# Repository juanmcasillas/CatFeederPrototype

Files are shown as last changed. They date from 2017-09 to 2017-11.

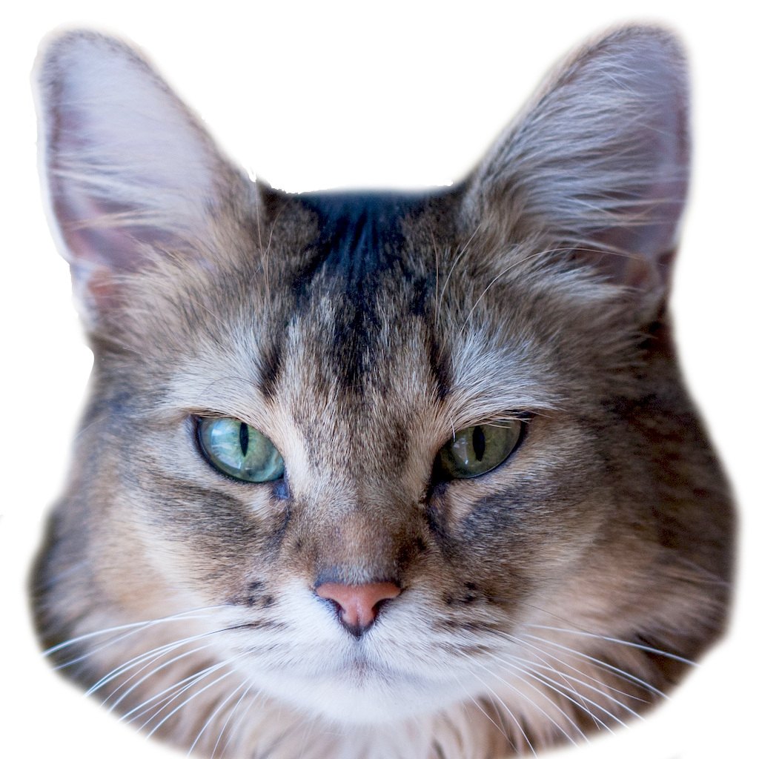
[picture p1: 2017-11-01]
python/webserver/www/photos/trans/neko.png

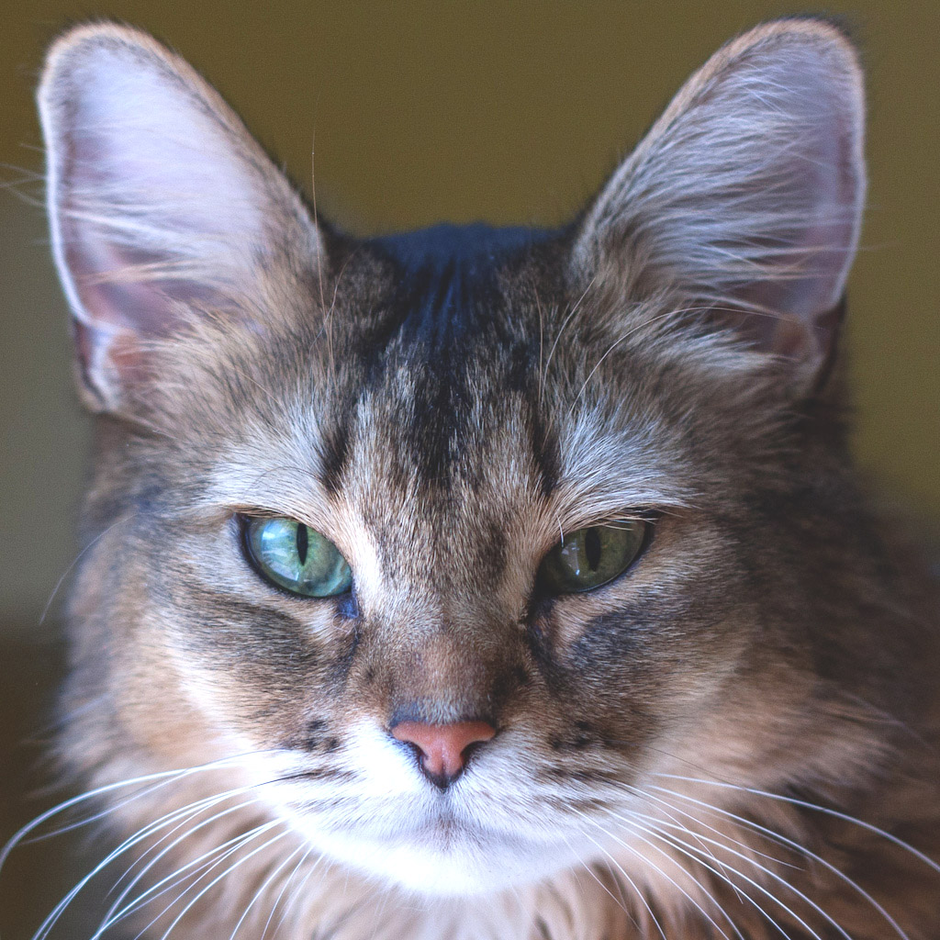
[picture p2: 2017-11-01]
python/webserver/www/photos/neko.jpg

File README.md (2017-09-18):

# CatFeeder
Automatic pet feeder, with artificial vision detection, rule based. Managed from a Web Server. Fully automated.

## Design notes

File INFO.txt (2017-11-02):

CatFeeder.

How to write a Cat Feeder, with lot of componentes.

pip install python-dateutil
pip install nanpy
sudo pip install git+https://github.com/dpallot/simple-websocket-server.git
pip install pytz
pip install tzlocal
  
------------------
1) CAT RECOGNIZER
------------------

IDS

01  ELI
02  FIRULAIS
03  NEKO

GOAL: recognize what of the three cats are lurking arround.

Using opencv2 (3.1.0) on raspberry Pi 3 with camera module 2.0 (raspbian jessie)

We have to train the classifier with the cats. So we need a source of
images. We can create a video, or add a bunch of images. So the flow:

[VIDEO] -> Convert to Images -> Train -> [Match]

[Match] can be realtime (VIDEO) or by picture (OFFLINE).

process_video.py
----------------

Get a video, extract cat faces, dump in the filesystem.

train_video.py
--------------

do the same thing, but trains a whole video. This is useful for one cat,
but we need to train 3 different videos (three cats) so work on that.

train_images.py
test_images.py

Nanpy:

git clone https://github.com/nanpy/nanpy-firmware.git
cd nanpy-firmware
./configure.sh

Managing a DC motor with Arduino
(Extracted from a CD ROM)

How to move it:

ARDUINO_PWM_IN	ARDUINO_DIRA_IN ARDUINO_DIRB_IN		GIRO
	5v				5v				0v				left
	5v				0v				5v				right
	5v				0v				0v				stop
	5v				5v				5v				NOT_ALLOWED
	0v				x				x				stop

https://ardubasic.wordpress.com/2014/05/23/control-de-motores-de-cc-con-l293d/
http://communityofrobots.com/tutorial/kawal/how-drive-dc-motor-using-l293d-arduino

OPENCV_PYTHON (windows)

set PATH=C:\Python27\DLLs;%PATH%

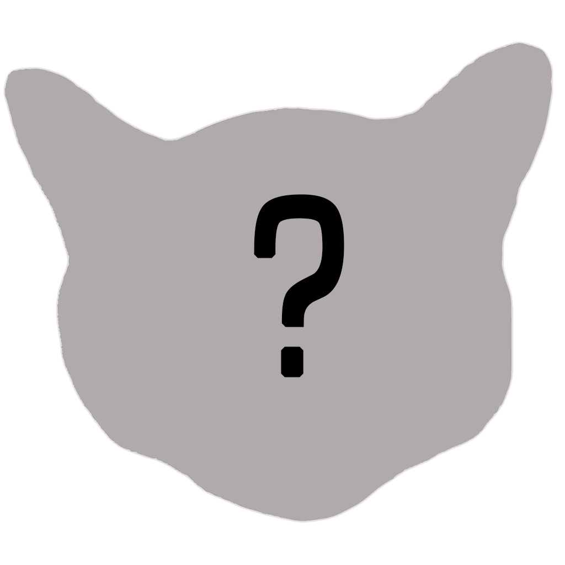
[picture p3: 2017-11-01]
python/webserver/www/photos/trans/unknown.png

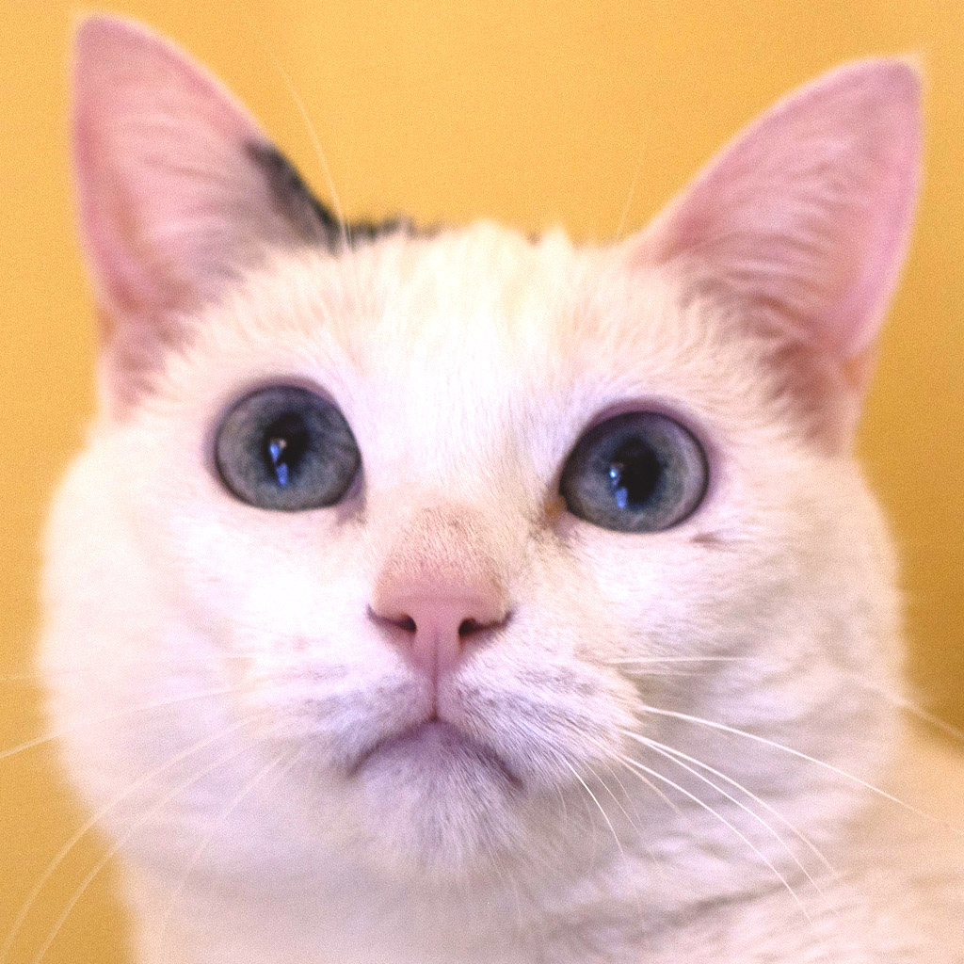
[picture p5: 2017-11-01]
python/webserver/www/photos/eli.jpg

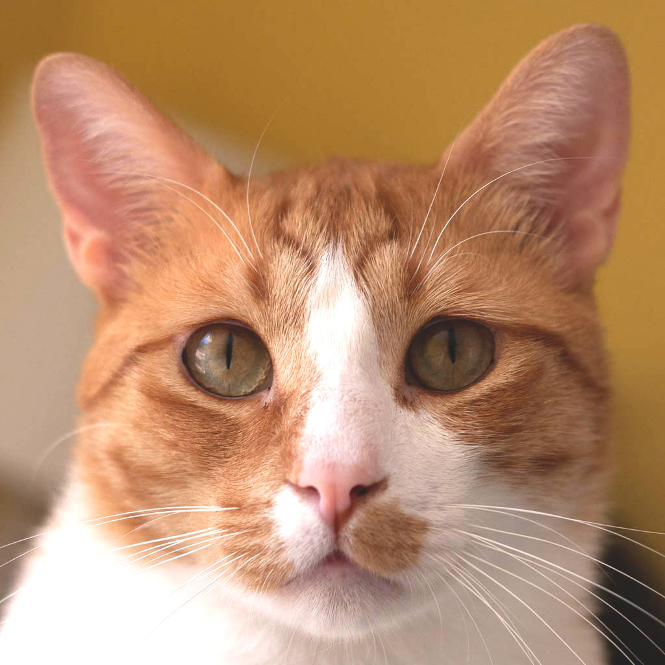
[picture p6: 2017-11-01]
python/webserver/www/photos/firulais.jpg

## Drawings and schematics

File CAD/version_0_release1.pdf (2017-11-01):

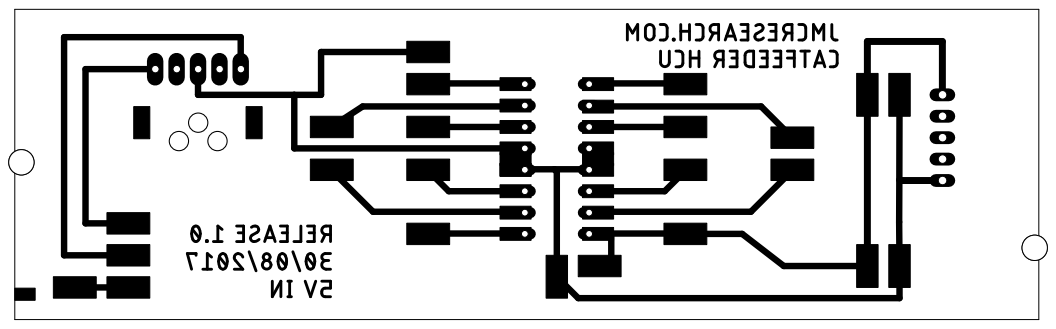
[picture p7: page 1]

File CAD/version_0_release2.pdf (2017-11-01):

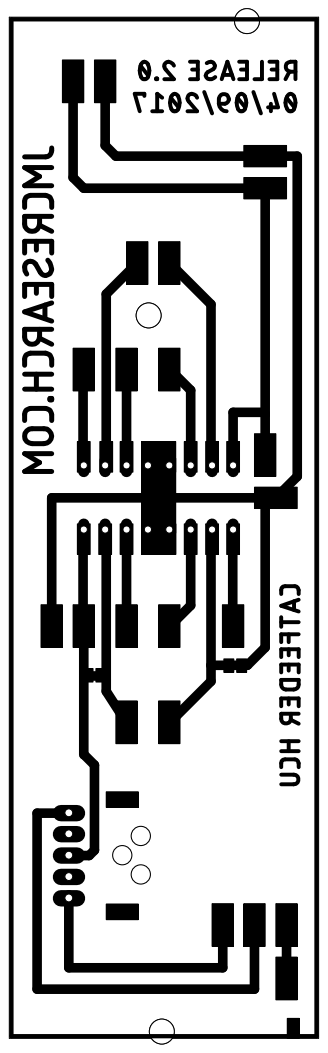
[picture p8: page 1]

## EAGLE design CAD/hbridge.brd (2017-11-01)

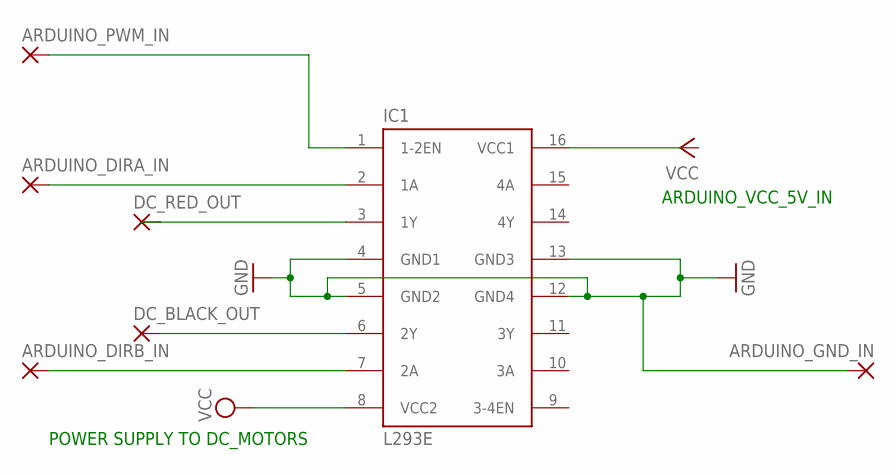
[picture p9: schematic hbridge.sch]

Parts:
ARDUINO_DIRA_IN: SMD2; SMD1,27-2,54
ARDUINO_DIRB_IN: SMD2; SMD1,27-2,54
ARDUINO_GND_IN: SMD2; SMD1,27-2,54
ARDUINO_PWM_IN: SMD2; SMD1,27-2,54
DC_BLACK_OUT: SMD2; SMD1,27-2,54
DC_RED_OUT: SMD2; SMD1,27-2,54
IC1: L293E; DIL16

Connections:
GND: ARDUINO_GND_IN.1, IC1.4 (GND1), IC1.5 (GND2), IC1.12 (GND4), IC1.13 (GND3)
unnamed: ARDUINO_PWM_IN.1, IC1.1 (1-2EN)
unnamed: DC_RED_OUT.1, IC1.3 (1Y)
unnamed: DC_BLACK_OUT.1, IC1.6 (2Y)
unnamed: ARDUINO_DIRA_IN.1, IC1.2 (1A)
unnamed: ARDUINO_DIRB_IN.1, IC1.7 (2A)
VCC: IC1.8 (VCC2)

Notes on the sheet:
POWER SUPPLY TO DC_MOTORS
ARDUINO_VCC_5V_IN

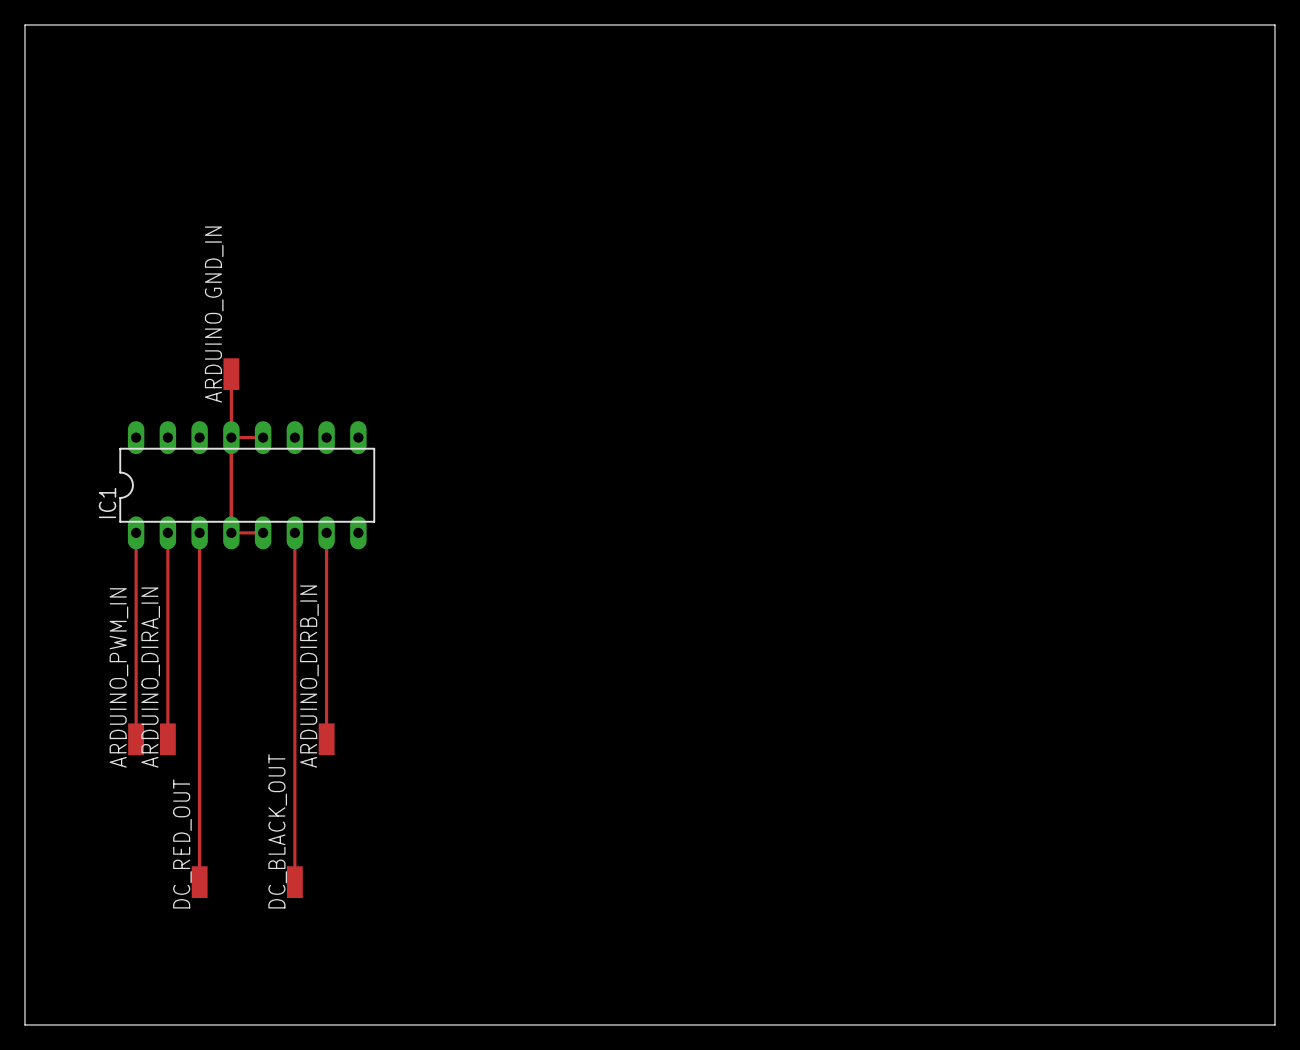
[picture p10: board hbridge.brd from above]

Board: 2 copper layers, 100.0 x 80.0 mm, 7 parts (0 on the bottom side), 6 nets.

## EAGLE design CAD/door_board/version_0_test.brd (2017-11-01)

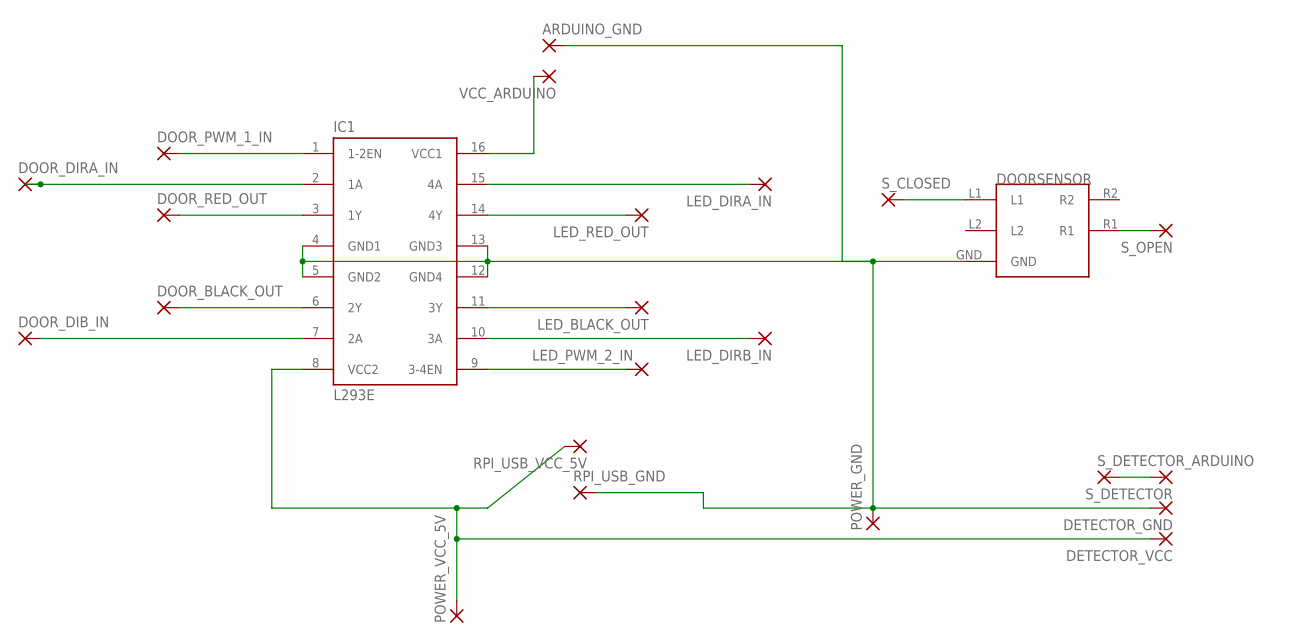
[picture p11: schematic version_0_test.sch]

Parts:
ARDUINO_GND: SMD5; SMD2,54-5,08
DETECTOR_GND: SMD5; SMD2,54-5,08
DETECTOR_VCC: SMD5; SMD2,54-5,08
DOORSENSOR: DOORSENSOR
DOOR_BLACK_OUT: SMD5; SMD2,54-5,08
DOOR_DIB_IN: SMD5; SMD2,54-5,08
DOOR_DIRA_IN: SMD5; SMD2,54-5,08
DOOR_PWM_1_IN: SMD5; SMD2,54-5,08
DOOR_RED_OUT: SMD5; SMD2,54-5,08
IC1: L293E; DIL16
LED_BLACK_OUT: SMD5; SMD2,54-5,08
LED_DIRA_IN: SMD5; SMD2,54-5,08
LED_DIRB_IN: SMD5; SMD2,54-5,08
LED_PWM_2_IN: SMD5; SMD2,54-5,08
LED_RED_OUT: SMD5; SMD2,54-5,08
POWER_GND: SMD5; SMD2,54-5,08
POWER_VCC_5V: SMD5; SMD2,54-5,08
RPI_USB_GND: SMD5; SMD2,54-5,08
RPI_USB_VCC_5V: SMD5; SMD2,54-5,08
S_CLOSED: SMD5; SMD2,54-5,08
S_DETECTOR: SMD5; SMD2,54-5,08
S_DETECTOR_ARDUINO: SMD5; SMD2,54-5,08
S_OPEN: SMD5; SMD2,54-5,08
VCC_ARDUINO: SMD5; SMD2,54-5,08

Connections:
GND: ARDUINO_GND.1, DETECTOR_GND.1, DOORSENSOR.GND, IC1.4 (GND1), IC1.5 (GND2), IC1.12 (GND4), IC1.13 (GND3), POWER_GND.1, RPI_USB_GND.1
unnamed: S_DETECTOR.1, S_DETECTOR_ARDUINO.1
unnamed: DOORSENSOR.L1, S_CLOSED.1
unnamed: DOORSENSOR.R1, S_OPEN.1
unnamed: DOOR_BLACK_OUT.1, IC1.6 (2Y)
unnamed: DOOR_RED_OUT.1, IC1.3 (1Y)
unnamed: IC1.9 (3-4EN), LED_PWM_2_IN.1
unnamed: DOOR_PWM_1_IN.1, IC1.1 (1-2EN)
unnamed: DOOR_DIRA_IN.1, IC1.2 (1A)
unnamed: DOOR_DIB_IN.1, IC1.7 (2A)
unnamed: IC1.10 (3A), LED_DIRB_IN.1
unnamed: IC1.15 (4A), LED_DIRA_IN.1
unnamed: IC1.11 (3Y), LED_BLACK_OUT.1
unnamed: IC1.14 (4Y), LED_RED_OUT.1
VCC_ARDUINO: IC1.16 (VCC1), VCC_ARDUINO.1
VCC_MOTOR: DETECTOR_VCC.1, IC1.8 (VCC2), POWER_VCC_5V.1, RPI_USB_VCC_5V.1

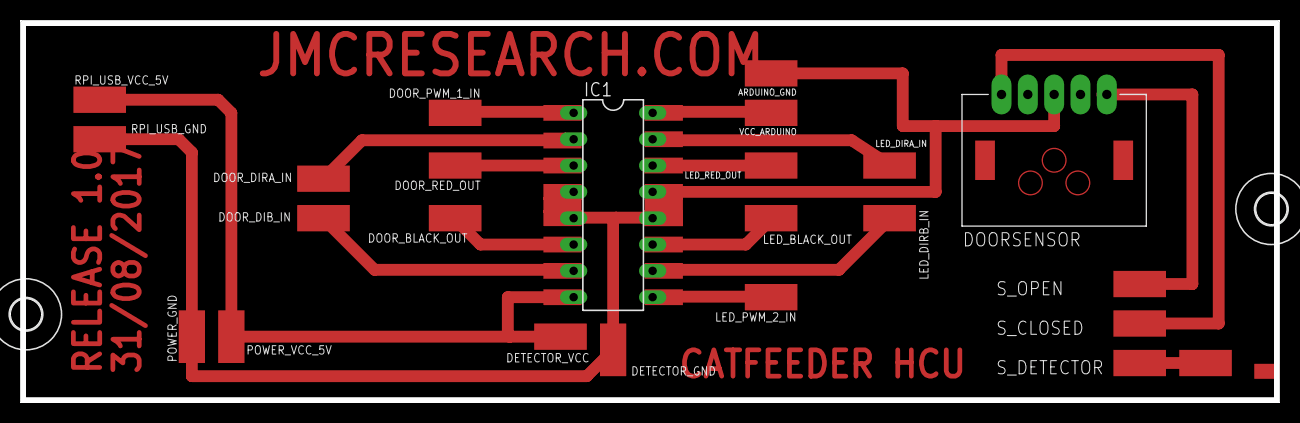
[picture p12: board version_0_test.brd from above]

Board: 2 copper layers, 121.4 x 36.8 mm, 26 parts (0 on the bottom side), 16 nets.

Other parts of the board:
U$1, U$2: 3,0

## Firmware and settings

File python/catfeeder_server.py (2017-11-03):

import time        
import datetime
import argparse
import os.path
import sys 
import webserver 
import hardware as HW
import threading
import logging
import logging.config
import wsock
import config
import detector
from db.rules import RuleService
import db
import hardware
import ipnetutils

class CatFeederServer:
    def __init__(self):
        
        self.info = config.O()
        self.info.pet = None
        self.info.photo = None
        self.info.start_meal = 0
        self.info.end_meal = 0
        self.info.ruleid = 0
        self.info.allowed = 0
        
        self.wait_time = 0
        detector.instance = detector.Detector() 
        

    def Define_Arguments(self):
        parser = argparse.ArgumentParser()
        parser.add_argument("-d", "--debug", help="Show debug info", action="store", default=logging.INFO)
        parser.add_argument("-o", "--host", help="Host running the server", action="store", default=ipnetutils.get_default_ip())
        parser.add_argument("-p", "--port", help="Port running the server", action="store", default=8088)
        parser.add_argument("-D", "--dummy", help="Run in dummy mode (no hardware attached)", action="store_true", default=False)
        #parser.add_argument("-wp", "--wsock_port", help="Port running the server (WSOCK)", action="store", default=8089)
        parser.add_argument("-s", "--serial_port", help="Serial Port for Arduino", action="store", default='/dev/cu.wchusbserial1a1130')
        
        parser.add_argument("database", help="DatabaseFile")
        args = parser.parse_args()
        
        return args

    def Do_Checks(self,args):
        if not os.path.exists(args.database):
            print "Can't open database: '%s'. Bailing out" % (args.database)
            sys.exit(1)
        
    def Setup_Environment(self,args):
        
        
        HW.LOCK = threading.Lock()
        HW.instance = HW.Interface(args.serial_port)
        db.Connect(args.database)   
        
        
        logging.basicConfig(level=args.debug,
                    format='%(asctime)s [%(levelname)s] %(message)s',
                    datefmt='%m/%d/%Y %H:%M:%S',
                    )
        
        logging.getLogger().setLevel(args.debug)
        root = logging.getLogger()
        hdlr = root.handlers[0]
        fmt = logging.Formatter('%(asctime)s [%(levelname)s] %(message)s')
        hdlr.setFormatter(fmt)
        fh = logging.FileHandler(config.LOG_FILE, mode=config.LOG_FILE_MODE)
        fh.setFormatter(fmt)
        root.addHandler(fh)
        logging.info("Setup_Environment() done.")
        
     
    def Start_WebServer(self,args):
        
        logging.info("Start_WebServer()")
        opts = webserver.www.Opts()
        opts.host = args.host
        opts.port = args.port
        opts.rootdir = config.www.root
        opts.no_dirlist = False
        opts.level = args.debug
        
        #opts.nocache = False
        #opts.cachedir = '.'
        #opts.dbfile = args.database
    
        #webserver.start_www_server_standalone(opts)
        webserver.start_www_server_thread(opts)
    
        # for testing the presence only
        # wsock.websocketserver_start(args.host,int(args.wsock_port))
    
    
    def Init_Hardware(self,args=None):
        """Reset the HW (Arduino) to default settings"""
        
        # for testing the interface. Works.
        #HW.instance.detector = 1
        #HW.instance.door_open = 1
        #HW.instance.door_closed = 1
        
        # start with door OPEN
        # lights off
        
        logging.info("Init_Hardware()")
        HW.instance.SetAmbientLight_OFF()
        #if HW.instance.GetSensorDoorClosed() == HW.instance.HIGH:
        #    logging.info("Closing Feeder (Opening door)")
        
        # for trainning, let the door OPEN
        if not config.TRAIN_MODE:
            HW.instance.OpenDoor()
        else:
            HW.instance.CloseDoor()
        HW.instance.SetStatusLED_OFF()
        
    
    def Init_Detector(self,args):
        """init the OPENCV interface"""
        logging.info("Init_Detector() (waitting %d seconds for Camera Init)" % config.CAMERA_WAIT_TIME)
        detector.instance.Setup()
    
    
    def SaveEvent(self):
        e = db.Event()
        e.start = self.info.start_meal
        e.end =   self.info.end_meal
        e.rule =  self.info.ruleid
        e.petid = self.info.pet.id
        e.allowed = self.info.allowed
        e.photo   = self.info.photo
 
        db.EventService().Insert(e)
        db.Commit()
    
    
    def Run_Automatic(self):
        """do the operation cycle here. Remember that this run inside a loop and can be interrupted by MANUAL STATUS"""
        
        if HW.STATE == HW.AUTO and HW.AUTO_STATE == HW.AUTO_INIT and HW.instance.GetActivationState():
            #cat enters in the CatFeeder
            HW.instance.SetAmbientLight_ON()
            pet,photo = detector.instance.Identify()
            if not photo:
                photo = detector.instance.GetPhoto()
            HW.instance.SetAmbientLight_OFF()
    
            if pet:
                self.info.pet = pet
                self.info.photo = photo
                
                logging.info("Detected pet %s" % self.info.pet.name)

                self.info.start_meal =  db.FormatDateTime(datetime.datetime.now())
                ruleid = db.RuleService().CheckRules(self.info.pet.name)
                if ruleid:
                    HW.SetAutoState(HW.AUTO_OPEN)
                    if not config.TRAIN_MODE:
                        HW.instance.CloseDoor() # open feeder
                    self.info.ruleid = ruleid
                    self.info.allowed = 1
                else:
                    # pet is not allowed to eat notify and don' change state.
                    HW.SetAutoState(HW.AUTO_REJECT)
                    self.info.allowed = 0
                    logging.info("Pet %s is not allowed to eat" % self.info.pet.name)
            else:
                # manage unknown pet (problem detection)
                self.info.pet = db.PetService().Load(config.pets.UNKNOWN_PET)
                self.info.photo = photo
                self.info.start_meal =  db.FormatDateTime(datetime.datetime.now())
                self.info.end_meal =  db.FormatDateTime(datetime.datetime.now())
                self.info.allowed = 0
                logging.info("Unknown cat found. Taking photo and saving event. Done")
                HW.SetAutoState(HW.AUTO_REJECT)
                self.LogState()
                self.SaveEvent()      
                
        if HW.STATE == HW.AUTO and HW.AUTO_STATE == HW.AUTO_OPEN and not HW.instance.GetActivationState():
            if not config.TRAIN_MODE:
                HW.instance.OpenDoor() # close feeder
            HW.SetAutoState(HW.AUTO_WAIT)
            self.LogState()
            self.wait_time = time.time()
            logging.info("Pet stops eating. Done %s" % self.info.pet.name)
            self.info.end_meal =  db.FormatDateTime(datetime.datetime.now())
            self.SaveEvent()
 
        if HW.STATE == HW.AUTO and HW.AUTO_STATE == HW.AUTO_REJECT and not HW.instance.GetActivationState():
            HW.SetAutoState(HW.AUTO_WAIT)
            self.LogState()
            self.wait_time = time.time()
            logging.info("Rejected pet goes away Done %s" % self.info.pet.name)
            self.info.end_meal =  db.FormatDateTime(datetime.datetime.now())
            self.SaveEvent()
            
        if HW.STATE == HW.AUTO and HW.AUTO_STATE == HW.AUTO_WAIT:
            if time.time() - self.wait_time > config.WAIT_STATE_TIMEOUT:
                HW.SetAutoState(HW.AUTO_INIT)
                self.LogState()
                logging.info("Wait done. Going out")
                
            else:
                logging.info("Waitting state - stabilize sensors")
                time.sleep(config.WAIT_STATE_SLEEP)
            
   
    def Run_Manual(self):
        """the manual operation. Does nothing, because it's controlled by the web"""
        pass

    def LogState(self):
        global HW
        if HW.STATE == HW.AUTO:
            logging.info("CatFeeder %s/%s" % (HW.STATE, HW.AUTO_STATE))
        else:
            logging.info("CatFeeder State: %s", HW.STATE)    
        

if __name__ == "__main__":
    
    
    # raspberry run
    # python catfeeder_server.py catfeeder.db --serial_port='' --host=0.0.0.0

    server = CatFeederServer()
    args = server.Define_Arguments()
    server.Do_Checks(args)

    # configure dummy interface
    
    if args.dummy:
        logging.info("Using DUMMY Hardware interface (for devel)")
        hardware.Interface = hardware.ArduinoInterfaceMock
        
   
    server.Setup_Environment(args)
    server.Init_Detector(args) # wait for cam stabilization & pir (arduino).
    server.Init_Hardware(args)
    server.Start_WebServer(args)
    logging.info("Server started!")
    
    if config.TRAIN_MODE:
        logging.info("Trainning mode activated. Don't move the DOOR")
      
    with HW.LOCK:
        HW.STATE = HW.AUTO
    
    server.LogState()
    
    while True:    
       
        # this should be removed.
        
        if HW.STATE == HW.AUTO:
            server.Run_Automatic()
        else:
            server.LogState()
            server.Run_Manual()
            if HW.Timeout():
                logging.info("Timeout Expired, returning to AUTO")
                with HW.LOCK:
                    HW.STATE = HW.AUTO
                    HW.AUTO_STATE = HW.AUTO_INIT
                    server.LogState()
                server.Init_Hardware()
                    
        time.sleep(config.SERVER_SLEEP) # 1 second

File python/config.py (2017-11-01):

import re
from datetime import timedelta
from string import Formatter

#from check_pi import *

class O: 
    def __init__(self): pass
    
colors = O()
colors.event_not_allowed = 'red'

www = O()
www.generic_title = 'Cat Feeder: '
www.root = 'webserver/www'

photodir = '%s/snaps' % www.root # photos to store things.

last_image = '%s/last_image.png' % photodir # last stored image
test_image = 'testimage.png' # use for mock values

LOG_FILE = 'catfeeder.log'
LOG_FILE_MODE = "w+" # don't append, create new

TRAIN_MODE=True #let the door open

#
# timeout seconds in MANUAL MODE
#
SERVER_SLEEP = 1 #seconds
STATE_TIMEOUT = 30 # seconds
STATE_TIMEOUT = 10 # seconds (for test) MANUAL STATE.
WAIT_STATE_TIMEOUT  = 5 # seconds
WAIT_STATE_SLEEP = 1 # seconds
IDENTIFY_TIMEOUT = 10 # seconds
CAMERA_WAIT_TIME = 10 # seconds

# detector config

PERCENT_MATCH = 80
PERCENT_MATCH_THRESHOLD = 5
FRAMES_MATCH = 15



arduino = O()
arduino.detector_timeout  = 30 # seconds 
arduino.delay_pir_init    = 6 # seconds
arduino.light_max_power   = 200 # pwm
arduino.motor_max_power   = 200 # pwm

#
# database cats to load
#
CAT_DB_ITEMS = [ 'firulais','neko', 'eli' ]


# for foor loop arduino.motor_delay = 10
#if IsRaspberry():
#    arduino.motor_delay   = 45
 
arduino.motor_delay = 800 # ms    


pets = O()
pets.UNKNOWN_PET = -1 # the unknown pet (non identified)

def PathToURL(path):
    if not path:
        return None
    p = re.sub("^%s" % www.root ,"",path)
    return p
    
camera = O()
camera.width = 800
camera.height = 608
camera.fps = 30
camera.rotation = 180

def StrUptime():
    return strfdelta(timedelta(seconds = uptime()))

def uptime():  
    with open('/proc/uptime', 'r') as f:
        uptime_seconds = float(f.readline().split()[0])
        #uptime_string = str(timedelta(seconds = uptime_seconds))
        return uptime_seconds
    
    
#https://stackoverflow.com/questions/538666/python-format-timedelta-to-string
def strfdelta(tdelta, fmt='{D:02}d {H:02}h {M:02}m {S:02}s', inputtype='timedelta'):
    """Convert a datetime.timedelta object or a regular number to a custom-
    formatted string, just like the stftime() method does for datetime.datetime
    objects.

    The fmt argument allows custom formatting to be specified.  Fields can 
    include seconds, minutes, hours, days, and weeks.  Each field is optional.

    Some examples:
        '{D:02}d {H:02}h {M:02}m {S:02}s' --> '05d 08h 04m 02s' (default)
        '{W}w {D}d {H}:{M:02}:{S:02}'     --> '4w 5d 8:04:02'
        '{D:2}d {H:2}:{M:02}:{S:02}'      --> ' 5d  8:04:02'
        '{H}h {S}s'                       --> '72h 800s'

    The inputtype argument allows tdelta to be a regular number instead of the  
    default, which is a datetime.timedelta object.  Valid inputtype strings: 
        's', 'seconds', 
        'm', 'minutes', 
        'h', 'hours', 
        'd', 'days', 
        'w', 'weeks'
    """

    # Convert tdelta to integer seconds.
    if inputtype == 'timedelta':
        remainder = int(tdelta.total_seconds())
    elif inputtype in ['s', 'seconds']:
        remainder = int(tdelta)
    elif inputtype in ['m', 'minutes']:
        remainder = int(tdelta)*60
    elif inputtype in ['h', 'hours']:
        remainder = int(tdelta)*3600
    elif inputtype in ['d', 'days']:
        remainder = int(tdelta)*86400
    elif inputtype in ['w', 'weeks']:
        remainder = int(tdelta)*604800

    f = Formatter()
    desired_fields = [field_tuple[1] for field_tuple in f.parse(fmt)]
    possible_fields = ('W', 'D', 'H', 'M', 'S')
    constants = {'W': 604800, 'D': 86400, 'H': 3600, 'M': 60, 'S': 1}
    values = {}
    for field in possible_fields:
        if field in desired_fields and field in constants:
            values[field], remainder = divmod(remainder, constants[field])
    return f.format(fmt, **values)

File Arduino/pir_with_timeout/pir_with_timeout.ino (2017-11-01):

/*
 * S_DETECTOR (white with back) D2
 * 
 */

const int PIN_S_DETECTOR  = 2;
const int PIN_ARDUINO_LED  = 13;

int  timeout;
unsigned long time_stamp;
unsigned long time_delta;
int PIR_STATE;


void setup() {  
    Serial.begin(115200);
    pinMode( PIN_ARDUINO_LED, OUTPUT) ;
    pinMode (PIN_S_DETECTOR, INPUT);
    delay(6000);  
    Serial.println("ready to work");

  timeout = 30; // seconds without activity
  time_stamp = 0;
  time_delta = 0;
  PIR_STATE = 0; // no detection

}

void loop() {

  if (digitalRead(PIN_S_DETECTOR)) {
    PIR_STATE = 1;
    time_stamp = millis();

    digitalWrite(PIN_ARDUINO_LED, HIGH);
    delay(10);
    digitalWrite(PIN_ARDUINO_LED, LOW);
    delay(10);
    digitalWrite(PIN_ARDUINO_LED, HIGH);
  }
  
 
  time_delta = millis() - time_stamp; 

  if ((time_delta >= (timeout *1000)) && (PIR_STATE == 1)) {
    PIR_STATE = 0;
    digitalWrite(PIN_ARDUINO_LED, LOW);
  }
  
}

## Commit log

2017-11-01 Initial import
    [hbridge.brd, hbridge.sch, position_sensor.sch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]
2017-11-02 Tagged will all the code.
    [hbridge.brd, hbridge.sch, position_sensor.sch]
2017-11-02 Remove all unnecesary files
    [result_new.xlsx, results.csv, results.xlsx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]
